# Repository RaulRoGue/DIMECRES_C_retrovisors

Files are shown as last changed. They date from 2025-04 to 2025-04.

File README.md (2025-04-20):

View this project on [CADLAB.io](https://cadlab.io/project/28966). 

# DIMECRES_C_retrovisors
## Autors
- Nom 1 (@RaulRoGue)
- Nom 2 (@inesquiot)
## Versió - v1.0 ## Curs - Assignatura de Disseny de PCBs amb KiCad - [Curs 2024-2025]

## Objectiu
Dissenyar una placa de circuit imprès (PCB) capaç de gestionar diverses funcions relacionades amb el retrovisor d’un vehicle. Aquesta PCB ha d’incloure les següents característiques:

- Control del plegament i desplegament del retrovisor, mitjançant motors elèctrics que permetin modificar-ne la posició de manera automàtica.

- Ajust de l'orientació del mirall, també motoritzat, per adaptar-lo segons les necessitats del conductor.

- Integració d’un sensor de detecció de punts morts, que alerti el conductor de la presència de vehicles o obstacles en zones de visibilitat reduïda.

- Incorporació d’un sistema de calefacció, per evitar l'entelament del mirall en condicions de fred o humitat.

- Implementació d’una llum indicadora de direcció, sincronitzada amb els intermitents del vehicle per millorar la visibilitat i la seguretat en maniobres.

## Requisits i especificacions
- 3 motors (moviment de mirall vertical i horitzontal, i plegat del retrovisor) amb
els seus finals de carrera.
- Calefactor del mirall.
- Sensor digital de detecció d’angle mort i llum indicadora.

## Diagrama de blocs
Diagrama blocs
## Taula de components
| Descripció | Manufacturer Number | Package | Datasheet | Proveïdor | Unitats |
|---|---|---|---|---|---|
| Driver | L298N | Multipower15 | [Enllaç](https://www.mouser.es/datasheet/2/389/l298-1849437.pdf) | Mouser | 1 |
| Microcontrolador|PIC18F4480| 40-Pin PDIP |[Enllaç](https://www.mouser.es/datasheet/2/268/41159e-3443038.pdf)| Mouser | 1 |
| CAN Transceiver| MCP2551 | Soic-8 |[Enllaç](https://www.mouser.es/datasheet/2/268/20001667G-3441642.pdf)| Mouser | 1 |
| Rele SPDT| FN01B | | [Enllaç](https://docs.rs-online.com/df01/0900766b8158318b.pdf) | RS Amidata | 2 | 
| Rele DPDT | G6S-2F| | [Enllaç](https://docs.rs-online.com/f19f/0900766b813679a7.pdf) | Rs Amidara | 1 | 
| OpAmp | ADA4511-2 | Soic-8 |[Enllaç](https://www.analog.com/media/en/technical-documentation/data-sheets/ada4511-2.pdf) | Analog Devices | 1 |
| Conv. DC/DC Buck | LM2596 | TO-263  | [Enllaç](https://www.ti.com/lit/ds/symlink/lm2596.pdf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) | Texas Instruments | 1 | 
| Regulador 5V | LT1117-5 | TO-263 | [Enllaç](https://www.ti.com/lit/ds/symlink/lm1117.pdf?ts=1742626115453&ref_url=https%253A%252F%252Feu.mouser.com%252F) | Texas Instruments | 1 |
| Diode Schottky | SS3P5 | SMP | [Enllaç](https://www.vishay.com/docs/88997/ss3p5.pdf)| Mouser | 1 | 
| Transistors BJT | DTC144EE-TP |  SOT523 | [Enllaç](https://eu.mouser.com/datasheet/2/258/DTC144EE_SOT_523_-3422355.pdf) | Mouser | 3 | 
| Sensor | CH201 | | [Enllaç](https://www.mouser.com/catalog/specsheets/TDK_10012020_DS-000379-CH201-v1.1.pdf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) | Mouser | 1 |
| Regulador 1.8V | ADM7160 | 5-TSOT | [Enllaç](https://www.analog.com/media/en/technical-documentation/data-sheets/ADM7160.pdf) | Analog Devices | 1 |
| Diodes Circulació | 1N5817 | DO-41 | [Enllaç](https://www.mouser.es/datasheet/2/389/1n5817-1848842.pdf) | Mouser | 3 | 
| Diodes Drivers | 1N5822 | DO-201AD | [Enllaç](https://www.mouser.es/datasheet/2/389/1n5822-1848813.pdf) | Mouser | 8 | 
| Convertidor voltatge | LSF0002 | DTQ(X2S0N) | [Enllaç](https://www.ti.com/lit/ds/symlink/lsf0002.pdf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) | Texas Instruments | 1 |
| Led Angle Mort | LS R976-NR-1 | 0805 (2012) | [Enllaç](https://www.mouser.es/datasheet/2/588/asset_pdf_5057921-3418987.pdf) | Mouser | 1 | 
| Led Alimentació | LTST-C170GKT | 0805 (2012) | [Enllaç](https://www.mouser.es/datasheet/2/239/Lite_On_LTST_C170GKT-1175235.pdf) | Mouser | 1 | 
| Connectors | 1548128 | | [Enllaç](https://www.mouser.es/ProductDetail/Phoenix-Contact/1548128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) | Mouser | 6 | 
| Botons | PTS647SN50SMTR2 LFS | | [Enllaç](https://www.ckswitches.com/media/2567/pts647.pdf) | Mouser | 6 | 
| Cristall | ABLS2-4.000MHz-B4Y-T | HC-49-US | [Enllaç](https://www.mouser.es/datasheet/2/3/ABLS2-1775116.pdf) | Mouser | 1 | 
| DE9 | DE-9S-1A8N-A197 | | [Enllaç](https://www.mouser.es/datasheet/2/578/original-3313093.pdf) | Mouser | 2 | 
| 
## Funcionalitats 
- [ ] Funció 1
- [ ] Funció 2
- [ ] Funció 3

## Historial de canvis 
| Data | Autor | Branch | Descripció |
|---|---|---|---|
| 2025-03-20 | Raul | `main` | Creació del projecte |
| 2025-03-21 | Raul | `main` | Llista materials | 
| 2025-03-23 | Raul | `main` | Sch. Regulador+Driver |
| 2025-03-23 | Ines | `main` | Sch. Microcontrolador |
| 2025-03-23 | Ines | `main` | Bus Can |
| 2025-03-23 | Ines | `main` | Modificacio Sch - afegit resistències i capacitancies |
| 2025-03-25 | Raul | `main` |Act. Sch. |
| 2025-03-29 | Raul | `main` | Sch. Def. |
| 2025-03-31 | Raul | `main` | Layout v1 | 
| 2025-03-31 | Ines | `main` | Diagrama de Blocs definitiu |

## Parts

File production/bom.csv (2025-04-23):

Designator | Footprint | Quantity | Value | LCSC Part #
C1 | CP_Radial_D6.3mm_P2.50mm | 1 | 120u
C10, C11, C14, C20, C4, C8, C9 | 1206 | 7 | 100n
C12, C13 | 0805 | 2 | 15p
C15, C16, C17 | 1206 | 3 | 47n
C18 | 0805 | 1 | 1n
C19, C3 | 1206 | 2 | 4u7
C2, C6 | CP_Radial_D6.3mm_P2.50mm | 2 | 470u
C21, C22 | 0805 | 2 | 33n
C23 | 0805 | 1 | 100n
C5 | 0805 | 1 | 100u
D1 | D_SMP_DO-220AA | 1 | SS3P5
D10, D11, D12, D13, D14, D7, D8, D9 | D_DO-201AD_P15.24mm_Horizontal | 8 | 1N5822
D2 | 0805 | 1 | R_LED
D3, D5, D6 | D_DO-41_SOD81_P10.16mm_Horizontal | 3 | 1N5817
D4 | 0805 | 1 | G_LED
J10 | TerminalBlock_TE_282834-2_1x02_5,08mm_Horizontal | 1 | Vbat
J2, J5 | DSUB-9_Socket_Vertical_P2.77x2.84mm_MountingHoles | 2 | DE9_Pins
J3 | PinHeader_1x05_P2.54mm_Vertical | 1 | Conn_01x05_Pin
J4 | TerminalBlock_TE_282834-2_1x02_5,08mm_Horizontal | 1 | Motor3
J6 | TerminalBlock_TE_282834-2_1x02_5,08mm_Horizontal | 1 | Intermitente
J7 | TerminalBlock_TE_282834-2_1x02_5,08mm_Horizontal | 1 | Calentador
J8 | TerminalBlock_TE_282834-2_1x02_5,08mm_Horizontal | 1 | Motor2
J9 | TerminalBlock_TE_282834-2_1x02_5,08mm_Horizontal | 1 | Motor1
JP1 | PinHeader_1x03_P2.54mm_Vertical | 1 | Jumper_3_Open
L1 | 0805 | 1 | 33u
Q1, Q2, Q3 | SOT-523 | 3 | DTC144E
R1, R12, R14, R16, R17 | 1206 | 5 | 1k
R10, R11, R25, R26 | 0805 | 4 | 1K
R13, R15, R18, R19 | 1206 | 4 | 100k
R2 | 1206 | 1 | 3k9
R20 | 0805 | 1 | 100
R21 | 0805 | 1 | 150
R22, R23 | 0805 | 2 | 120
R24 | 0805 | 1 | 180
R3 | 1206 | 1 | 10k
R4, R5 | 1206 | 2 | 50m
R6 | 0805 | 1 | 60
R7 | 1206 | 1 | 15k
R9 | 1206 | 1 | 33k
SW1 | Relay_DPDT_Omron_G6S-2F | 1 | SW_DPDT_G6S
SW10 | SW_SPST_PTS647_Sx38 | 1 | SW_Push
SW2 | SW_SPST_PTS647_Sx38 | 1 | UN/FOLD
SW3 | SW_SPST_PTS647_Sx38 | 1 | HEAT
SW4 | SW_SPST_PTS647_Sx38 | 1 | UP
SW5 | SW_SPST_PTS647_Sx38 | 1 | DOWN
SW6 | SW_SPST_PTS647_Sx38 | 1 | LEFT
SW7 | SW_SPST_PTS647_Sx38 | 1 | RIGHT
SW8, SW9 | Relay_SPDT_HsinDa_Y14 | 2 | FN01B
U1 | CH201 | 1 | CH201
U10 | TO-263-3_TabPin2 | 1 | LM1117DT-5.0
U2 | TSOT-23-5 | 1 | ADM7160
U3 | TO-263-5_TabPin3 | 1 | LM2596S-ADJ
U4 | TO-220-15_P2.54x5.08mm_StaggerOdd_Lead4.58mm_Vertical | 1 | L298N
U5 | SOIC-8_3.9x4.9mm_P1.27mm | 1 | MCP2551-I-SN
U6 | SOIC-8_3.9x4.9mm_P1.27mm | 1 | ADA4511-2
U7 | DIP-40_W15.24mm | 1 | PIC18F4480-IP
U8 | LSF0002 | 1 | LSF0002
Y1 | Crystal_SMD_HC49-SD_Practica3 | 1 | Crystal

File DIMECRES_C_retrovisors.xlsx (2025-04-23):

Reference | Value | Datasheet | Footprint | Qty | DNP | LSCS
C1 | 120u | ~ | Capacitor_THT:CP_Radial_D6.3mm_P2.50mm | 1 |  | C261376
C2,C6 | 470u | ~ | Capacitor_THT:CP_Radial_D6.3mm_P2.50mm | 2 |  | C43328
C3,C19 | 4u7 | ~ | Capacitor_SMD:C_1206_3216Metric_Pad1.33x1.80mm_HandSolder | 2 |  | C1872 | TAULA DE PREUS DE COMPONENTS PER NÚMERO DE UNITATS
C4,C8,C9,C10,C11,C14,C20 | 100n | ~ | Capacitor_SMD:C_1206_3216Metric_Pad1.33x1.80mm_HandSolder | 7 |  | C1945
C5 | 100u | ~ | Capacitor_SMD:C_0805_2012Metric_Pad1.18x1.45mm_HandSolder | 1 |  | C141660 | unitats | x10 | x50 | x1.000 | x20.000
C12,C13 | 15p | ~ | Capacitor_SMD:C_0805_2012Metric_Pad1.18x1.45mm_HandSolder | 2 |  | C63339 | COMPONENTS (€/unitat)
C15,C16,C17 | 47n | ~ | Capacitor_SMD:C_1206_3216Metric_Pad1.33x1.80mm_HandSolder | 3 |  | C1870 | Microcontrolador: PIC18F4480-I/P | 7.270 | 7.270 | 7.270 | 7.270 | *DigiKey | PIC18F4480 (https://www.digikey.es/en/products/detail/microchip-technology/PIC18F4480-I-P/718243)
C18 | 1n | ~ | Capacitor_SMD:C_0805_2012Metric_Pad1.18x1.45mm_HandSolder | 1 |  | C1791 | Driver: L298N | 8.524 | 7.938 | 6.651 | 6.651 | *DigiKey | L298N (https://www.digikey.es/es/products/detail/stmicroelectronics/L298N/585918)
C21,C22 | 33n | ~ | Capacitor_SMD:C_0805_2012Metric_Pad1.18x1.45mm_HandSolder | 2 |  | C107150 | CAN Transceiver: MCP2551 | 1.250 | 1.042 | 1.026 | 1.026 | *DigiKey | MCP2551 (https://www.digikey.es/es/products/detail/microchip-technology/MCP2551-I-SN/509452)
C23 | 100n | ~ | Capacitor_SMD:C_0805_2012Metric_Pad1.18x1.45mm_HandSolder | 1 |  | C1711 | Rele SPDT: FN01B | 2.480 | 2.210 | 1.480 | 1.480 | *RS Amidata | FN01B (https://es.rs-online.com/web/p/reles-de-senal/0476757?searchId=290cb22d-e97d-4f3a-a323-c20805e55914&gb=s)
D1 | SS3P5 | ~ | Diode_SMD:D_SMP_DO-220AA | 1 |  | C7369110 | Rele DPDT: G6S-2F-DC5 | 3.209 | 2.960 | 2.545 | 2.545 | *DigiKey | G6S-2F-DC5 (https://www.digikey.es/es/products/detail/omron-electronics-inc-emc-div/G6S-2F-DC5/27496)
D2 | R_LED | ~ | LED_SMD:LED_0805_2012Metric_Pad1.15x1.40mm_HandSolder | 1 |  | C2899997 | OpAmp: ADA4511-2 | 2.210 | 2.210 | 1.210 | 1.170 | *DigiKey | ADA4511-2 (https://www.mouser.es/ProductDetail/Analog-Devices/ADA4511-2ARZ?qs=dbcCsuKDzFWR7kRkdhPUdQ%3D%3D)
D3,D5,D6 | 1N5817 | http://www.vishay.com/docs/88525/1n5817.pdf | Diode_THT:D_DO-41_SOD81_P10.16mm_Horizontal | 3 |  | C698892 | Conv. DC/DC Buck: LM2596T-ADJ/NOPB | 4.190 | 3.880 | 3.120 | 3.060 | *Mouser | LM2596ADJ (https://www.mouser.es/ProductDetail/Texas-Instruments/LM2596SX-ADJ-NOPB?qs=X1J7HmVL2ZGDNERsF5YBdQ%3D%3D)
D4 | G_LED | ~ | LED_SMD:LED_0805_2012Metric_Pad1.15x1.40mm_HandSolder | 1 |  | C125090 | Regulador 5V : LT1117CST-5 | 5.785 | 4.599 | 3.737 | 3.710 | *DigiKey | LT1117 (https://www.digikey.es/en/products/detail/analog-devices-inc/LT1117CM-5-PBF/)
D7,D8,D9,D10,D11,D12,D13,D14 | 1N5822 | http://www.vishay.com/docs/88526/1n5820.pdf | Diode_THT:D_DO-201AD_P15.24mm_Horizontal | 8 |  |  | Diode Schottky: SS3P5-M3 | 0.154 | 0.154 | 0.100 | 0.071 | *DigiKey | SS3P5 (https://www.digikey.es/en/products/detail/vishay-general-semiconductor-diodes-division/SS3P5HM3-84A/4495002)
J2,J5 | DE9_Pins | ~ | Connector_Dsub:DSUB-9_Socket_Vertical_P2.77x2.84mm_MountingHoles | 2 |  | C77831 | Transistors BJT: DTC144EE-TP | 0.128 | 0.128 | 0.051 | 0.031 | *DigiKey | DTC144EE (https://www.digikey.es/en/products/detail/mcc-micro-commercial-components/DTC144EE-TP/857327)
J3 | Conn_01x05_Pin | ~ | Connector_PinHeader_2.54mm:PinHeader_1x05_P2.54mm_Vertical | 1 |  | C2337 | Sensor: CH201 | 5.420 | 5.420 | 4.980 | 4.980 | *Mouser | CH201 (https://www.mouser.es/ProductDetail/TDK-InvenSense/CH201-00ABR?qs=hWgE7mdIu5SG9AjHdakrVw%3D%3D)
J4 | Motor3 | ~ | PracticasKiCad:TerminalBlock_TE_282834-2_1x02_5,08mm_Horizontal | 1 |  | C9900170820 | Regulador 1.8V: ADM7160AUJZ-1.8-R | 1.580 | 1.390 | 0.826 | 0.754 | *Mouser | ADM7160 (https://www.mouser.es/ProductDetail/Analog-Devices/ADM7160AUJZ-1.8-R7?qs=%252BrH4t%252BeVZ2NHqIoVkrMpCQ%3D%3D)
J6 | Intermitente | ~ | PracticasKiCad:TerminalBlock_TE_282834-2_1x02_5,08mm_Horizontal | 1 |  | C9900170820 | Diodes Circulació: 1N5817 | 0.165 | 0.165 | 0.089 | 0.046 | *DigiKey | 1N5817 (https://www.digikey.es/en/products/detail/stmicroelectronics/1N5817/770963)
J7 | Calentador | ~ | PracticasKiCad:TerminalBlock_TE_282834-2_1x02_5,08mm_Horizontal | 1 |  | C9900170820 | Diodes Drivers: 1N5822 | 0.204 | 0.204 | 0.121 | 0.090 | *Mouser | 1N5822 (https://www.mouser.es/ProductDetail/STMicroelectronics/1N5822?qs=JV7lzlMm3yJ50hlrGV6%252BnQ%3D%3D)
J8 | Motor2 | ~ | PracticasKiCad:TerminalBlock_TE_282834-2_1x02_5,08mm_Horizontal | 1 |  | C9900170820 | Led Angle Mort: Ls R976-NR-1 | 0.102 | 0.102 | 0.051 | 0.037 | *DigiKey | LED ROIG (https://www.digikey.es/en/products/detail/ams-osram-usa-inc/LS-R976-NR-1-0-20-R18/1227987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)
J9 | Motor1 | ~ | PracticasKiCad:TerminalBlock_TE_282834-2_1x02_5,08mm_Horizontal | 1 |  | C9900170820 | Led Alimentació: LTST-C170GKT | 0.105 | 0.105 | 0.052 | 0.038 | *Mouser | LED VERD (https://www.mouser.es/ProductDetail/LITEON/LTST-C170GKT?qs=%2FSqKn2EfXQSV5aRij3YIfQ%3D%3D)
J10 | Vbat | ~ | PracticasKiCad:TerminalBlock_TE_282834-2_1x02_5,08mm_Horizontal | 1 |  | C9900170820 | Connectors | 0.939 | 0.939 | 0.939 | 0.939 | *Mouser | CONNECTOR (https://www.mouser.es/ProductDetail/Phoenix-Contact/1548128?qs=ulEaXIWI0c87QOzP9yohxA%3D%3D)
JP1 | Jumper_3_Open | ~ | Connector_PinHeader_2.54mm:PinHeader_1x03_P2.54mm_Vertical | 1 |  | C2337 | Botons | 0.179 | 0.179 | 0.153 | 0.105 | *Mouser | BOTONS (https://www.mouser.es/ProductDetail/CK/PTS647SN50SMTR2-LFS?qs=Imq1NPwxi75fXjNwFzf38w%3D%3D)
L1 | 33u | ~ | Inductor_SMD:L_0805_2012Metric_Pad1.05x1.20mm_HandSolder | 1 |  | C412010 | Convertidor Voltatge : LSF0002 | 0.248 | 0.221 | 0.168 | 0.137 | *Mouser | LSF0002 (https://www.mouser.es/ProductDetail/Texas-Instruments/LSF0002DTQR?qs=i8QVZAFTkqSFGlrqVB4k9w%3D%3D)
Q1,Q2,Q3 | DTC144E |  | Package_TO_SOT_SMD:SOT-523 | 3 |  | C17296322 | Cristall | 0.279 | 0.253 | 0.207 | 0.171 | *Mouser | CRISTALL (https://www.mouser.es/ProductDetail/ABRACON/ABLS2-4.000MHz-B4Y-T?qs=DZ%2FvJMgWWIuMViH9oNkyhA%3D%3D)
R1,R12,R14,R16,R17 | 1k | ~ | Resistor_SMD:R_1206_3216Metric_Pad1.30x1.75mm_HandSolder | 5 |  | C4410 | DE9 | 5.333 | 4.760 | 4.531 | 4.531 | *DigiKey | DE9 (https://www.digikey.es/en/products/detail/jae-electronics/DE-9SF-T-N/5397179)
R2 | 3k9 | ~ | Resistor_SMD:R_1206_3216Metric_Pad1.30x1.75mm_HandSolder | 1 |  | C26042 | TOTAL COMPONENTS: (€/placa) | 65.35 | 60.882 | 52.0599 | 50.9639
R3 | 10k | ~ | Resistor_SMD:R_1206_3216Metric_Pad1.30x1.75mm_HandSolder | 1 |  | C17902 | TOTAL COMPONENTS | 653.5 | 3044.1 | 52059.9 | 1019278
R4,R5 | 50m | ~ | Resistor_SMD:R_1206_3216Metric_Pad1.30x1.75mm_HandSolder | 2 |  | C335234
R6 | 60 | ~ | Resistor_SMD:R_0805_2012Metric_Pad1.20x1.40mm_HandSolder | 1 |  | C2767521
R7 | 15k | ~ | Resistor_SMD:R_1206_3216Metric_Pad1.30x1.75mm_HandSolder | 1 |  | C25828
R9 | 33k | ~ | Resistor_SMD:R_1206_3216Metric_Pad1.30x1.75mm_HandSolder | 1 |  | C25660
R10,R11,R25,R26 | 1K | ~ | Resistor_SMD:R_0805_2012Metric_Pad1.20x1.40mm_HandSolder | 4 |  | C25623
R13,R15,R18,R19 | 100k | ~ | Resistor_SMD:R_1206_3216Metric_Pad1.30x1.75mm_HandSolder | 4 |  | C25647
R20 | 100 | ~ | Resistor_SMD:R_0805_2012Metric_Pad1.20x1.40mm_HandSolder | 1 |  | C25277
R21 | 150 | ~ | Resistor_SMD:R_0805_2012Metric_Pad1.20x1.40mm_HandSolder | 1 |  | C25283
R22,R23 | 120 | ~ | Resistor_SMD:R_0805_2012Metric_Pad1.20x1.40mm_HandSolder | 2 |  | C25280 | TAULADE PREUS PER CADA PCB DEPENENT DEL TIPUS DE MUNTATGE
R24 | 180 | ~ | Resistor_SMD:R_0805_2012Metric_Pad1.20x1.40mm_HandSolder | 1 |  | C1339
SW1 | SW_DPDT_G6S | ~ | Relay_SMD:Relay_DPDT_Omron_G6S-2F | 1 |  | C16707 |  | muntatge manual amb terminis curts d'entrega |  |  |  | muntatge industrial amb temps de lliurament llarg |  |  | PCB | Capacitats | Resistències | Inductància | Altres | Total
SW2 | UN/FOLD | ~ | Button_Switch_SMD:SW_SPST_PTS647_Sx38 | 1 |  | C2799414 | unitats | x10 |  | x50 |  | x1.000 |  | x20.000 | x1000 | - | - | - | 43876.5 | 43876.5
SW3 | HEAT | ~ | Button_Switch_SMD:SW_SPST_PTS647_Sx38 | 1 |  | C2799414 | Components | 653.5 |  | 3044.1 |  | 43876.5 |  | 928538 | x20000 | 7942 | 52 | 364 | 920180 | 928538
SW4 | UP | ~ | Button_Switch_SMD:SW_SPST_PTS647_Sx38 | 1 |  | C2799414 | PCB | 18.8 |  | 64.7 |  | 502.8 |  | 7749.8
SW5 | DOWN | ~ | Button_Switch_SMD:SW_SPST_PTS647_Sx38 | 1 |  | C2799414 | Stencils | 7 |  | 7 |  | x |  | x
SW6 | LEFT | ~ | Button_Switch_SMD:SW_SPST_PTS647_Sx38 | 1 |  | C2799414 | Muntatge | x |  | x |  | 3515.34 |  | 9097.65
SW7 | RIGHT | ~ | Button_Switch_SMD:SW_SPST_PTS647_Sx38 | 1 |  | C2799414 | TOTAL PCB | 679.3 |  | 3115.8 |  | 47894.64 |  | 945385.45
SW8,SW9 | FN01B |  | Relay_THT:Relay_SPDT_HsinDa_Y14 | 2 |  |  | PREU Unitari | 67.93 |  | 62.316 |  | 47.89464 |  | 47.2692725
SW10 | SW_Push | ~ | Button_Switch_SMD:SW_SPST_PTS647_Sx38 | 1 |  | C2799414
U1 | CH201 |  | PracticasKiCad:CH201 | 1 |  | C1513114
U2 | ADM7160 |  | Package_TO_SOT_SMD:TSOT-23-5 | 1 |  | C658467
U3 | LM2596S-ADJ | http://www.ti.com/lit/ds/symlink/lm2596.pdf | Package_TO_SOT_SMD:TO-263-5_TabPin3 | 1 |  | C9900011164
U4 | L298N | http://www.st.com/st-web-ui/static/active/en/resource/technical/document/datasheet/CD00000240.pdf | Package_TO_SOT_THT:TO-220-15_P2.54x5.08mm_StaggerOdd_Lead4.58mm_Vertical | 1 |  | C19922
U5 | MCP2551-I-SN | http://ww1.microchip.com/downloads/en/devicedoc/21667d.pdf | Package_SO:SOIC-8_3.9x4.9mm_P1.27mm | 1 |  | C7376
U6 | ADA4511-2 | https://www.analog.com/media/en/technical-documentation/data-sheets/ada4522-1_4522-2_4522-4.pdf | Package_SO:SOIC-8_3.9x4.9mm_P1.27mm | 1 |  | C22441753
U7 | PIC18F4480-IP | http://ww1.microchip.com/downloads/en/DeviceDoc/39637d.pdf | Package_DIP:DIP-40_W15.24mm | 1 |  | C647983
U8 | LSF0002 |  | PracticasKiCad:LSF0002 | 1
U10 | LM1117DT-5.0 | http://www.ti.com/lit/ds/symlink/lm1117.pdf | Package_TO_SOT_SMD:TO-263-3_TabPin2 | 1 |  | C2867691
Y1 | Crystal | ~ | PracticasKiCad:Crystal_SMD_HC49-SD_Practica3 | 1 |  | C5542957

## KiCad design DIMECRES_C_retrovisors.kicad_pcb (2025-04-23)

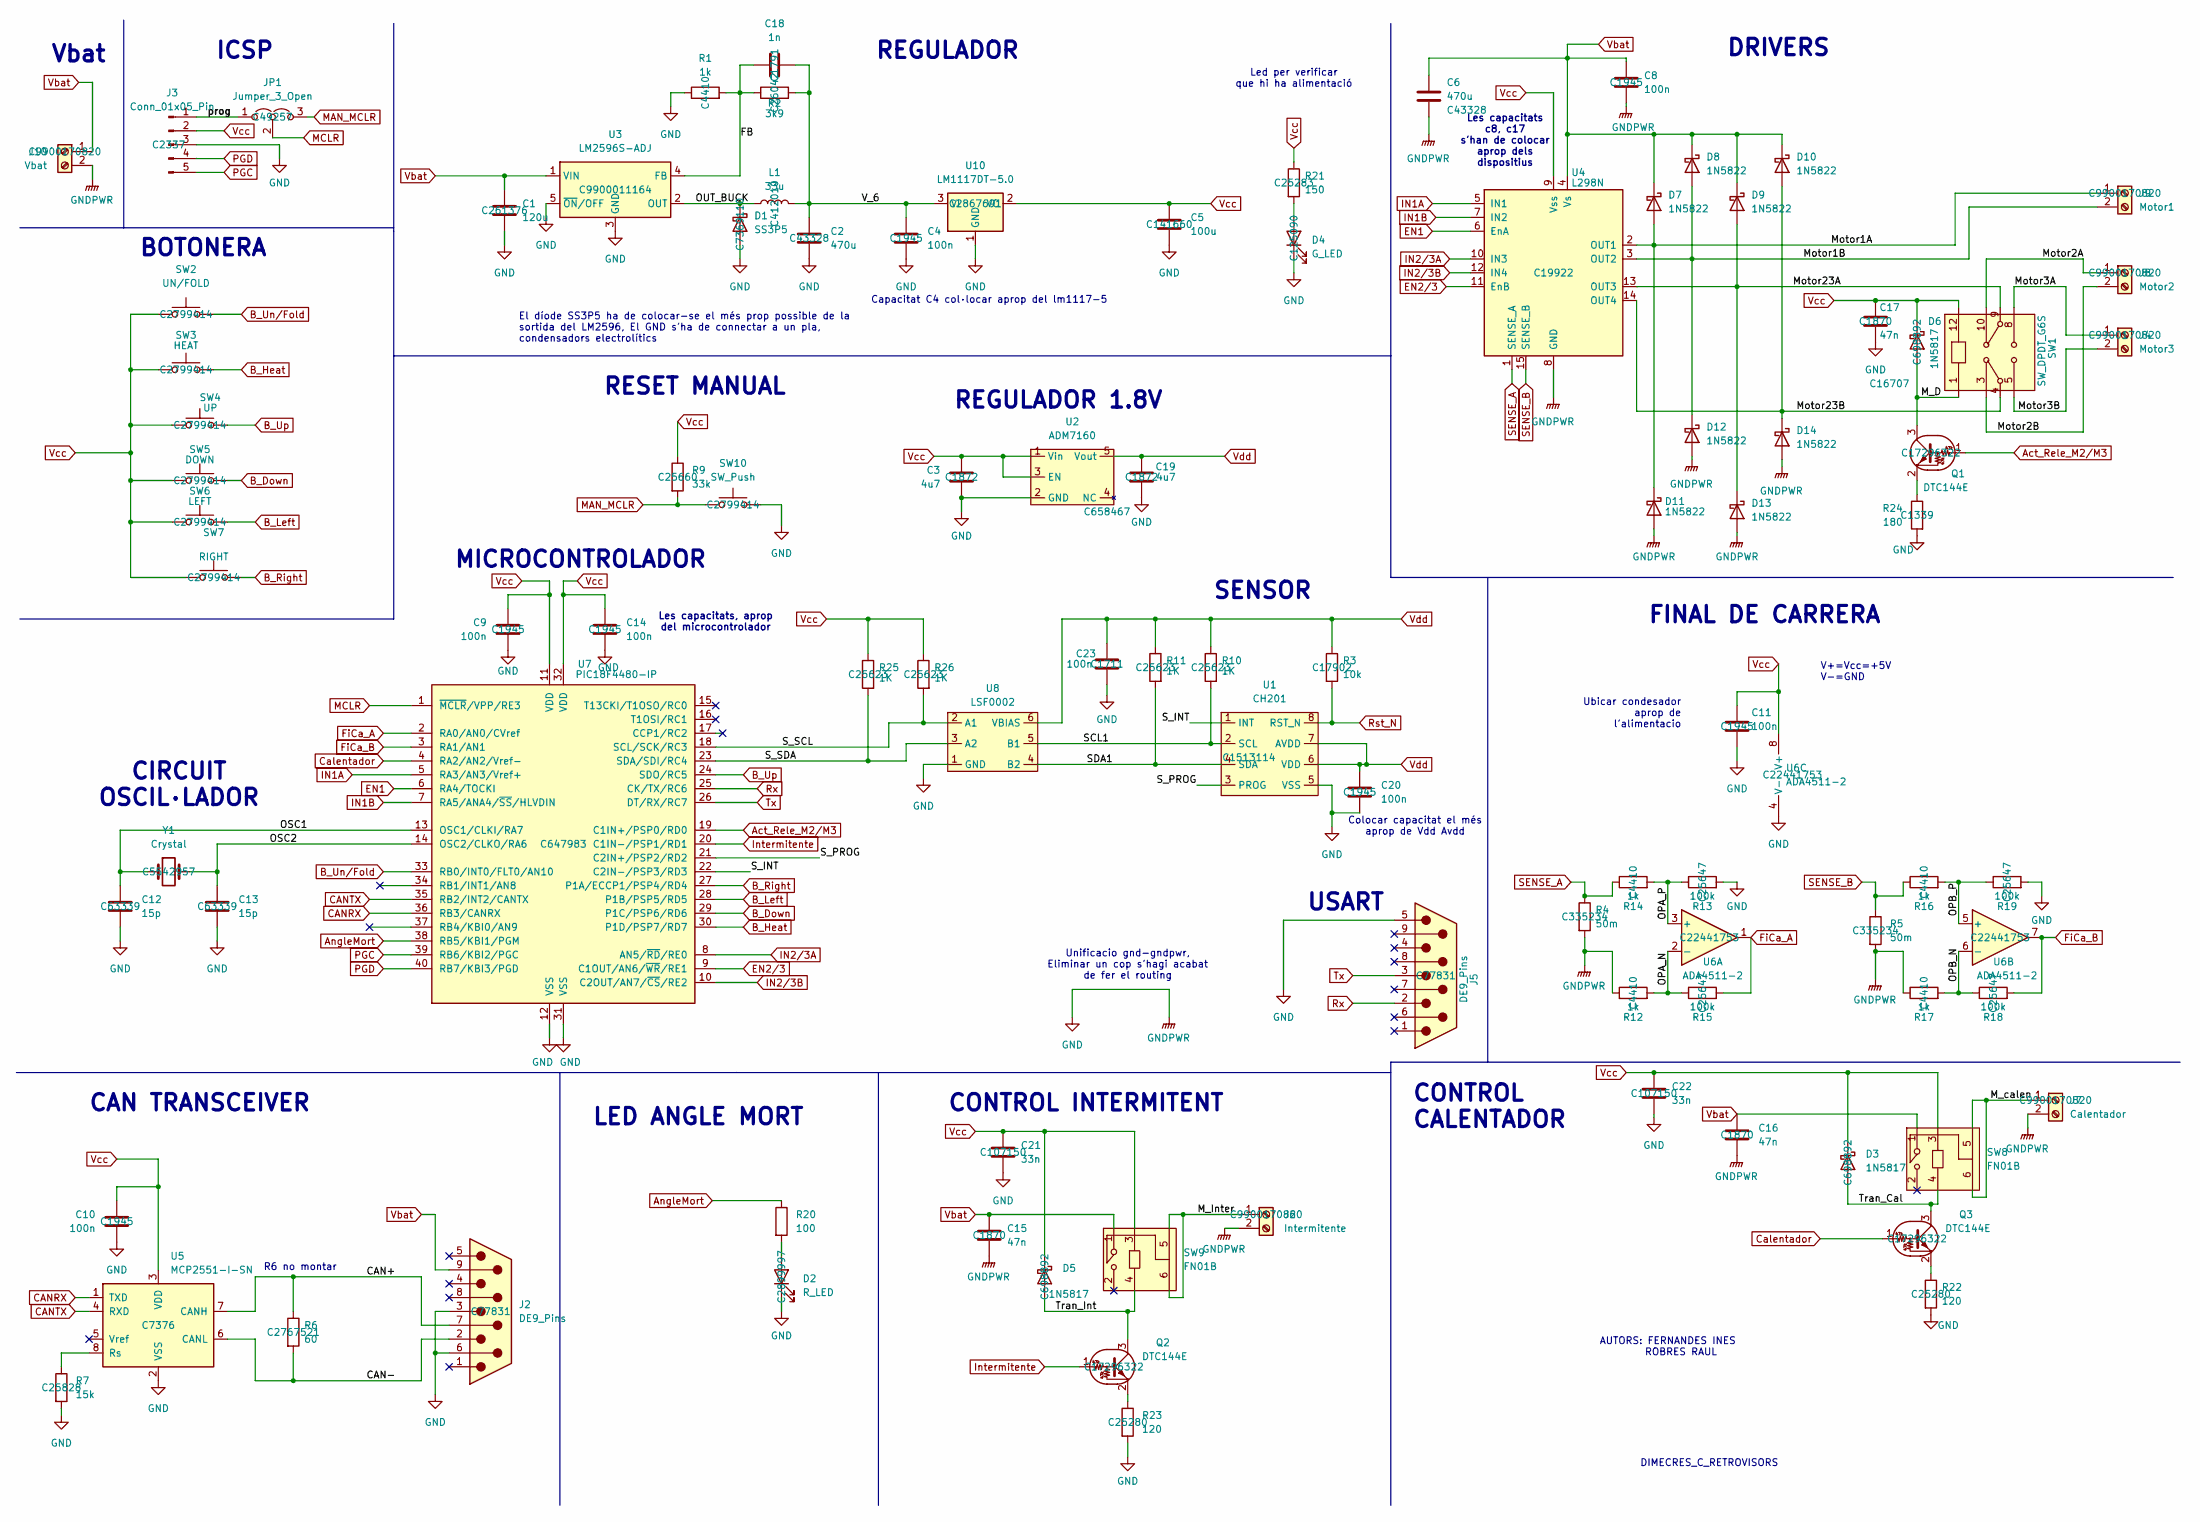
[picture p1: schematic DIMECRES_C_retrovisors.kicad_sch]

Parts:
C1: 120u; CP_Radial_D6.3mm_P2.50mm
C2, C6: 470u; CP_Radial_D6.3mm_P2.50mm
C3, C19: 4u7; C_1206_3216Metric_Pad1.33x1.80mm_HandSolder
C4, C8, C9, C10, C11, C14, C20: 100n; C_1206_3216Metric_Pad1.33x1.80mm_HandSolder
C5: 100u; C_0805_2012Metric_Pad1.18x1.45mm_HandSolder
C12, C13: 15p; C_0805_2012Metric_Pad1.18x1.45mm_HandSolder
C15, C16, C17: 47n; C_1206_3216Metric_Pad1.33x1.80mm_HandSolder
C18: 1n; C_0805_2012Metric_Pad1.18x1.45mm_HandSolder
C21, C22: 33n; C_0805_2012Metric_Pad1.18x1.45mm_HandSolder
C23: 100n; C_0805_2012Metric_Pad1.18x1.45mm_HandSolder
D1: SS3P5; D_SMP_DO-220AA
D2: R_LED; LED_0805_2012Metric_Pad1.15x1.40mm_HandSolder
D3, D5, D6: 1N5817; D_DO-41_SOD81_P10.16mm_Horizontal
D4: G_LED; LED_0805_2012Metric_Pad1.15x1.40mm_HandSolder
D7, D8, D9, D10, D11, D12, D13, D14: 1N5822; D_DO-201AD_P15.24mm_Horizontal
J2, J5: DE9_Pins; DSUB-9_Socket_Vertical_P2.77x2.84mm_MountingHoles
J3: Conn_01x05_Pin; PinHeader_1x05_P2.54mm_Vertical
J4: Motor3; TerminalBlock_TE_282834-2_1x02_5,08mm_Horizontal
J6: Intermitente; TerminalBlock_TE_282834-2_1x02_5,08mm_Horizontal
J7: Calentador; TerminalBlock_TE_282834-2_1x02_5,08mm_Horizontal
J8: Motor2; TerminalBlock_TE_282834-2_1x02_5,08mm_Horizontal
J9: Motor1; TerminalBlock_TE_282834-2_1x02_5,08mm_Horizontal
J10: Vbat; TerminalBlock_TE_282834-2_1x02_5,08mm_Horizontal
JP1: Jumper_3_Open; PinHeader_1x03_P2.54mm_Vertical
L1: 33u; L_0805_2012Metric_Pad1.05x1.20mm_HandSolder
Q1, Q2, Q3: DTC144E; SOT-523
R1, R12, R14, R16, R17: 1k; R_1206_3216Metric_Pad1.30x1.75mm_HandSolder
R2: 3k9; R_1206_3216Metric_Pad1.30x1.75mm_HandSolder
R3: 10k; R_1206_3216Metric_Pad1.30x1.75mm_HandSolder
R4, R5: 50m; R_1206_3216Metric_Pad1.30x1.75mm_HandSolder
R6: 60; R_0805_2012Metric_Pad1.20x1.40mm_HandSolder
R7: 15k; R_1206_3216Metric_Pad1.30x1.75mm_HandSolder
R9: 33k; R_1206_3216Metric_Pad1.30x1.75mm_HandSolder
R10, R11, R25, R26: 1K; R_0805_2012Metric_Pad1.20x1.40mm_HandSolder
R13, R15, R18, R19: 100k; R_1206_3216Metric_Pad1.30x1.75mm_HandSolder
R20: 100; R_0805_2012Metric_Pad1.20x1.40mm_HandSolder
R21: 150; R_0805_2012Metric_Pad1.20x1.40mm_HandSolder
R22, R23: 120; R_0805_2012Metric_Pad1.20x1.40mm_HandSolder
R24: 180; R_0805_2012Metric_Pad1.20x1.40mm_HandSolder
SW1: SW_DPDT_G6S; Relay_DPDT_Omron_G6S-2F
SW2: UN/FOLD; SW_SPST_PTS647_Sx38
SW3: HEAT; SW_SPST_PTS647_Sx38
SW4: UP; SW_SPST_PTS647_Sx38
SW5: DOWN; SW_SPST_PTS647_Sx38
SW6: LEFT; SW_SPST_PTS647_Sx38
SW7: RIGHT; SW_SPST_PTS647_Sx38
SW8, SW9: FN01B; Relay_SPDT_HsinDa_Y14
SW10: SW_Push; SW_SPST_PTS647_Sx38
U1: CH201
U2: ADM7160; TSOT-23-5
U3: LM2596S-ADJ; TO-263-5_TabPin3
U4: L298N; TO-220-15_P2.54x5.08mm_StaggerOdd_Lead4.58mm_Vertical
U5: MCP2551-I-SN; SOIC-8_3.9x4.9mm_P1.27mm
U6: ADA4511-2; SOIC-8_3.9x4.9mm_P1.27mm
U7: PIC18F4480-IP; DIP-40_W15.24mm
U8: LSF0002
U10: LM1117DT-5.0; TO-263-3_TabPin2
Y1: Crystal; Crystal_SMD_HC49-SD_Practica3

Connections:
/CAN+: J2.7, R6.1, U5.7 (CANH)
/CAN-: J2.2, R6.2, U5.6 (CANL)
/FB: C18.1, R1.2, R2.1, U3.4 (FB)
/M_D: D6.2 (A), Q1.3 (C), SW1.1
/M_Inter: J6.1, SW9.5, SW9.6
/M_calen: J7.1, SW8.5, SW8.6
/Motor1A: D7.2 (A), D11.1 (K), J9.1, U4.2 (OUT1)
/Motor1B: D8.2 (A), D12.1 (K), J9.2, U4.3 (OUT2)
/Motor2A: J8.1, SW1.10
/Motor2B: J8.2, SW1.3
/Motor3A: J4.1, SW1.8
/Motor3B: J4.2, SW1.5
/Motor23A: D9.2 (A), D13.1 (K), SW1.9, U4.13 (OUT3)
/Motor23B: D10.2 (A), D14.1 (K), SW1.4, U4.14 (OUT4)
/OPA_N: R12.2, R15.1, U6.2 (-)
/OPA_P: R13.1, R14.2, U6.3 (+)
/OPB_N: R17.2, R18.1, U6.6 (-)
/OPB_P: R16.2, R19.1, U6.5 (+)
/OSC1: C12.1, U7.13 (OSC1/CLKI/RA7), Y1.1
/OSC2: C13.1, U7.14 (OSC2/CLKO/RA6), Y1.2
/OUT_BUCK: D1.1 (K), L1.1, U3.2 (OUT)
/SCL1: R10.2, U1.2 (SCL), U8.5 (B1)
/SDA1: R11.2, U1.4 (SDA), U8.4 (B2)
/S_INT: U1.1 (INT), U7.22 (C2IN-/PSP3/RD3)
/S_PROG: U1.3 (PROG), U7.21 (C2IN+/PSP2/RD2)
/S_SCL: R26.2, U7.18 (SCL/SCK/RC3), U8.2 (A1)
/S_SDA: R25.2, U7.23 (SDA/SDI/RC4), U8.3 (A2)
/Tran_Cal: D3.2 (A), Q3.3 (C), SW8.4
/Tran_Int: D5.2 (A), Q2.3 (C), SW9.4
/V_6: C2.1, C4.1, C18.2, L1.2, R2.2, U10.3 (VI)
/prog: J3.1, JP1.1 (A)
Act_Rele_M2/M3: Q1.1 (B), U7.19 (C1IN+/PSP0/RD0)
AngleMort: R20.1, U7.38 (RB5/KBI1/PGM)
B_Down: SW5.2, U7.29 (P1C/PSP6/RD6)
B_Heat: SW3.2, U7.30 (P1D/PSP7/RD7)
B_Left: SW6.2, U7.28 (P1B/PSP5/RD5)
B_Right: SW7.2, U7.27 (P1A/ECCP1/PSP4/RD4)
B_Un/Fold: SW2.2, U7.33 (RB0/INT0/FLT0/AN10)
B_Up: SW4.2, U7.24 (SDO/RC5)
CANRX: U5.1 (TXD), U7.36 (RB3/CANRX)
CANTX: U5.4 (RXD), U7.35 (RB2/INT2/CANTX)
Calentador: Q3.1 (B), U7.4 (RA2/AN2/Vref-)
EN1: U4.6 (EnA), U7.6 (RA4/TOCKI)
EN2/3: U4.11 (EnB), U7.9 (C1OUT/AN6/~WR/RE1)
FiCa_A: R15.2, U6.1, U7.2 (RA0/AN0/CVref)
FiCa_B: R18.2, U6.7, U7.3 (RA1/AN1)
GND: C1.2, C2.2, C3.2, C4.2, C5.2, C6.2, C8.2, C9.2, C10.2, C11.2, C12.2, C13.2, C14.2, C15.2, C16.2, C17.2, C19.2, C20.2, C21.2, C22.2, C23.2, D1.2 (A), D2.1 (K), D4.1 (K), D11.2 (A), D12.2 (A), D13.2 (A), D14.2 (A), J2.3, J2.6, J3.3, J5.5, J6.2, J7.2, J10.2, R1.1, R4.2, R5.2, R7.2, R12.1, R13.2, R17.1, R19.2, R22.2, R23.2, R24.2, SW10.2, U1.5 (VSS), U2.2 (GND), U3.3 (GND), U3.5 (~ON/OFF), U4.8 (GND), U5.2 (VSS), U6.4 (V-), U7.12 (VSS), U7.31 (VSS), U8.1 (GND), U10.1 (GND)
IN1A: U4.5 (IN1), U7.5 (RA3/AN3/Vref+)
IN1B: U4.7 (IN2), U7.7 (RA5/ANA4/~SS/HLVDIN)
IN2/3A: U4.10 (IN3), U7.8 (AN5/~RD/RE0)
IN2/3B: U4.12 (IN4), U7.10 (C2OUT/AN7/~CS/RE2)
Intermitente: Q2.1 (B), U7.20 (C1IN-/PSP1/RD1)
MAN_MCLR: JP1.3 (B), R9.2, SW10.1
MCLR: JP1.2 (C), U7.1 (~MCLR/VPP/RE3)
unnamed: D2.2 (A), R20.2
unnamed: D4.2 (A), R21.2
unnamed: Q1.2 (E), R24.1
unnamed: Q2.2 (E), R23.1
unnamed: Q3.2 (E), R22.1
unnamed: R7.1, U5.8 (Rs)
PGC: J3.5, U7.39 (RB6/KBI2/PGC)
PGD: J3.4, U7.40 (RB7/KBI3/PGD)
Rst_N: R3.2, U1.8 (RST_N)
Rx: J5.2, U7.25 (CK/TX/RC6)
SENSE_A: R4.1, R14.1, U4.1 (SENSE_A)
SENSE_B: R5.1, R16.1, U4.15 (SENSE_B)
Tx: J5.3, U7.26 (DT/RX/RC7)
Vbat: C1.1, C6.1, C8.1, C15.1, C16.1, D7.1 (K), D8.1 (K), D9.1 (K), D10.1 (K), J2.9, J10.1, SW8.1, SW9.1, U3.1 (VIN), U4.4 (Vs)
Vcc: C3.1, C5.1, C9.1, C10.1, C11.1, C14.1, C17.1, C21.1, C22.1, D3.1 (K), D5.1 (K), D6.1 (K), J3.2, R9.1, R21.1, R25.1, R26.1, SW1.12, SW2.1, SW3.1, SW4.1, SW5.1, SW6.1, SW7.1, SW8.3, SW9.3, U2.1 (Vin), U2.3 (EN), U4.9 (Vss), U5.3 (VDD), U6.8 (V+), U7.11 (VDD), U7.32 (VDD), U10.2 (VO)
Vdd: C19.1, C20.1, C23.1, R3.1, R10.1, R11.1, U1.6 (VDD), U1.7 (AVDD), U2.5 (Vout), U8.6 (VBIAS)

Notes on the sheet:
REGULADOR 1.8V
R6 no montar
REGULADOR
Vbat
SENSOR
Unificacio gnd-gndpwr, Eliminar un cop s'hagi acabat de fer el routing
CIRCUIT OSCIL·LADOR
Les capacitats, aprop del microcontrolador
DIMECRES_C_RETROVISORS
MICROCONTROLADOR
DRIVERS
AUTORS: FERNANDES INES ROBRES RAUL
Colocar capacitat el més aprop de Vdd Avdd
CAN TRANSCEIVER
Les capacitats c8, c17 s'han de colocar aprop dels dispositius
CONTROL INTERMITENT
Ubicar condesador aprop de l'alimentacio
V+=Vcc=+5V V-=GND
Led per verificar que hi ha alimentació
LED ANGLE MORT
BOTONERA
Capacitat C4 col·locar aprop del lm1117-5
El díode SS3P5 ha de colocar-se el més prop possible de la sortida del LM2596, El GND s'ha de connectar a un pla, condensadors electrolítics
USART
CONTROL CALENTADOR
RESET MANUAL
FINAL DE CARRERA
ICSP

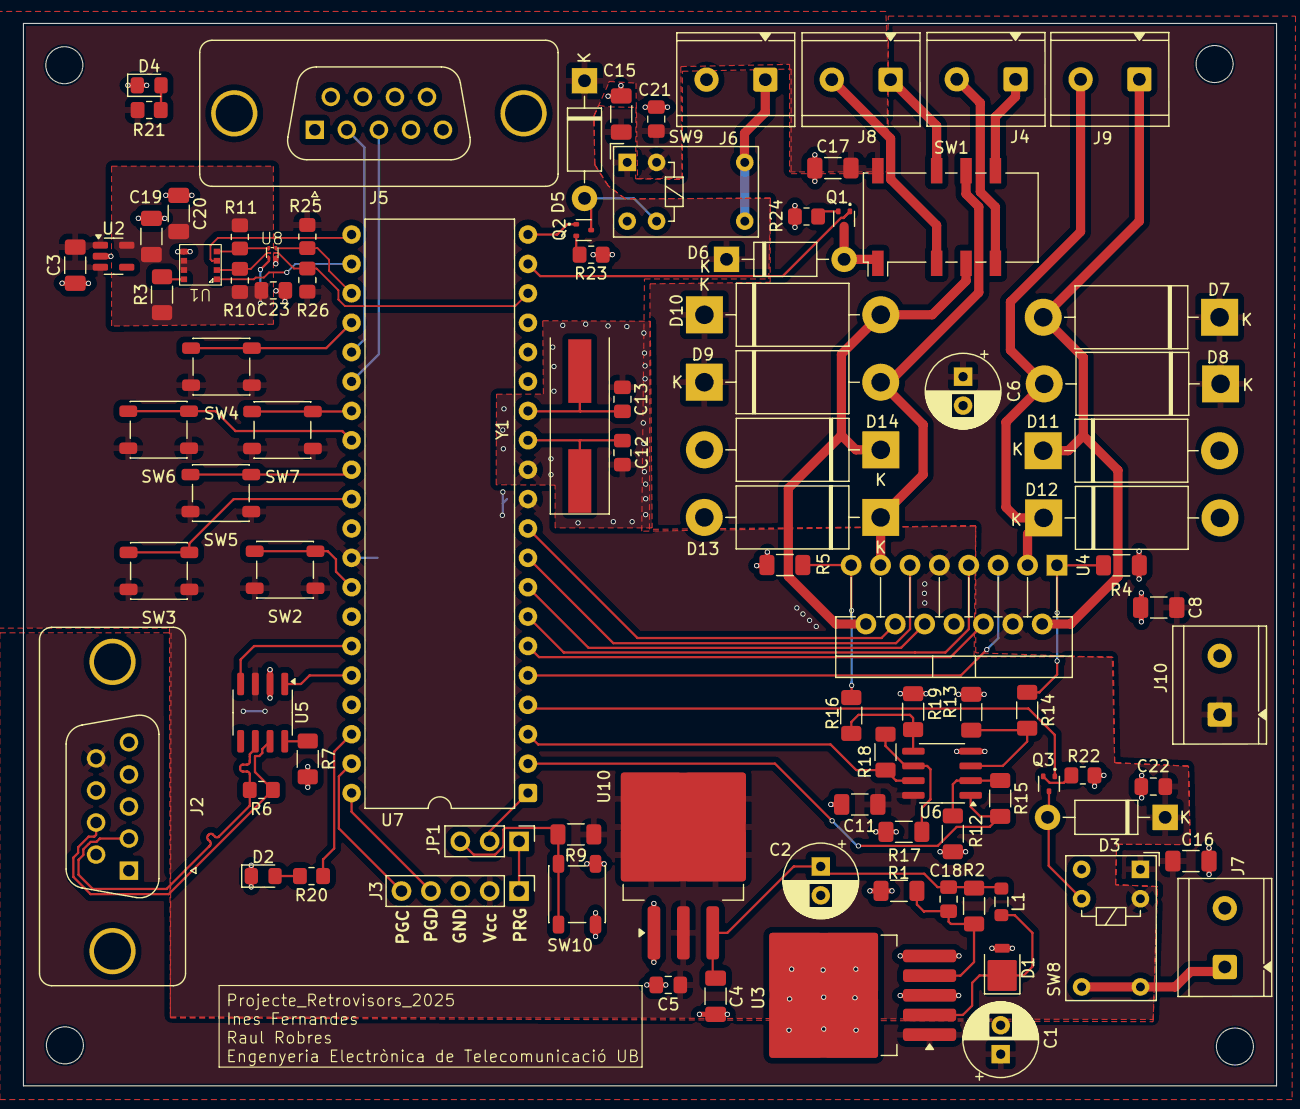
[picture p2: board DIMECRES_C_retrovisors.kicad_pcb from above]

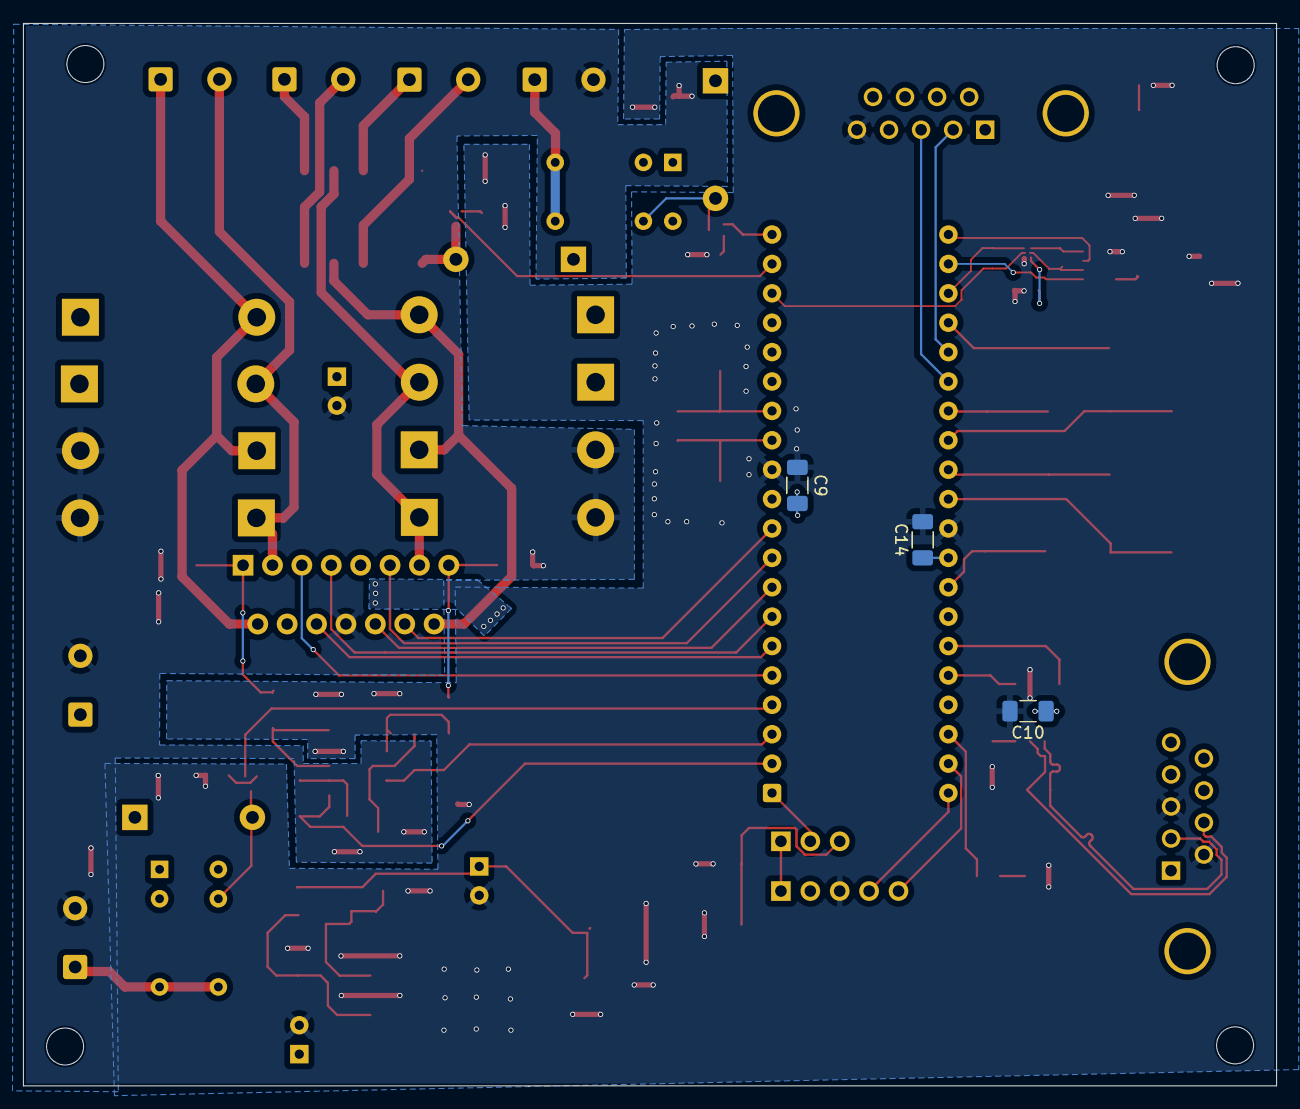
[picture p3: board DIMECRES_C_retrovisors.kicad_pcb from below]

Board: 2 copper layers, 108.3 x 91.8 mm, 95 parts (3 on the bottom side), 70 nets.

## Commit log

2025-03-19 Creacio projecte kicad
    [DIMECRES_C_retrovisors.kicad_pcb, DIMECRES_C_retrovisors.kicad_sch]
2025-03-20 Add schematic and pcb
    [DIMECRES_C_retrovisors.kicad_pcb, DIMECRES_C_retrovisors.kicad_sch]
2025-03-20 borrar todo
    [DIMECRES_C_retrovisors.kicad_pcb, DIMECRES_C_retrovisors.kicad_sch]
2025-03-20 Añadir sch+pcb
    [DIMECRES_C_retrovisors.kicad_pcb, DIMECRES_C_retrovisors.kicad_sch]
2025-03-20 prueba 2
    [DIMECRES_C_retrovisors.kicad_sch]
2025-03-22 Actualització llista material
2025-03-22 1/2Etapa reguladora
    [DIMECRES_C_retrovisors.kicad_sch]
2025-03-23 Regulador+1/3 Driver
    [DIMECRES_C_retrovisors.kicad_sch]
2025-03-23 Update README, change orientation of the BJT
    [DIMECRES_C_retrovisors.kicad_sch]
2025-03-24 Delete DIMECRES_C_retrovisors_24_03.kicad_sch
    nuevo modelo
    [DIMECRES_C_retrovisors_24_03.kicad_sch]
2025-03-24 Microcontrolador + edicion driver
    Esquematico Editado - driver + microcontrolador. Falta añadir sensores
    [DIMECRES_C_retrovisors.kicad_sch]
2025-03-24 Add diode + resistencia proteccio a MCLR
    Add diode + resistencia 10kOhms proteccio a MCLR. Resistencia Pull-up + diode de proteccio al pin MCLR
    [DIMECRES_C_retrovisors.kicad_sch]
2025-03-24 correccio errors
    [DIMECRES_C_retrovisors.kicad_sch]
2025-03-24 Upload sch
    [DIMECRES_C_retrovisors.kicad_sch]
2025-03-25 Update sch
    [DIMECRES_C_retrovisors.kicad_sch]
2025-03-25 Upd. sch. & Diag.
    [DIMECRES_C_retrovisors.kicad_sch]
2025-03-28 Up. sch.
    [DIMECRES_C_retrovisors.kicad_sch]
2025-03-29 Up de tot
    [DIMECRES_C_retrovisors.kicad_sch]
2025-03-29 UP SCH
    [DIMECRES_C_retrovisors.kicad_sch]
2025-03-30 Inicio Layout queda mucho aun...
    [DIMECRES_C_retrovisors.kicad_pcb, DIMECRES_C_retrovisors.kicad_sch]
2025-03-31 Todo el layout v1 ?
    [DIMECRES_C_retrovisors.kicad_pcb, DIMECRES_C_retrovisors.kicad_sch]
2025-04-01 Actu Layoutt
    [DIMECRES_C_retrovisors.kicad_pcb, DIMECRES_C_retrovisors.kicad_sch]
2025-04-02 Add files via upload
    Versió del diagrama de Blocs definitva. Incluint la distinció de les diferents Net Classes que tenim en el projecte. S'afegeixen colors per cadascuna i a mes a mes s'afegeix una llegenda que especifi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
2025-04-02 VERSIO DEL DIAGRAMA DE BLOCS SEPARAT PER CLASSES
    S'ha modificat el diagrama separant els tipus de classes que actualment tenim en el nostre projecte. Es diferencien les classes: power, analog i digital per colors i s'afegeix una llegenda que concre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
2025-04-03 Primeres MOdificacions Layout
    [DIMECRES_C_retrovisors.kicad_pcb]
2025-04-06 mod. lay.
    [DIMECRES_C_retrovisors.kicad_pcb]
2025-04-07 Modificacions Layout
    [DIMECRES_C_retrovisors.kicad_pcb]
2025-04-08 Proimeres correccions
    [DIMECRES_C_retrovisors.kicad_pcb, DIMECRES_C_retrovisors.kicad_sch]
2025-04-08 planos vcc
    [DIMECRES_C_retrovisors.kicad_pcb, DIMECRES_C_retrovisors.kicad_sch]
2025-04-08 Ns pero creo que asi se queda
    [DIMECRES_C_retrovisors.kicad_pcb]
2025-04-08 Asi se queda demomento
    [DIMECRES_C_retrovisors.kicad_pcb]
2025-04-09 Modificació de coses puntuals
    S'ha afegit el domini a la placa, s'han modificat algunes vies per tal de que sigui millor tan visualment com a nivell de funcionament dels components
2025-04-09 correccion errores
    [DIMECRES_C_retrovisors.kicad_pcb, DIMECRES_C_retrovisors.kicad_sch]
2025-04-14 De to
    [DIMECRES_C_retrovisors.kicad_pcb, DIMECRES_C_retrovisors.kicad_sch]
2025-04-20 ultims canvis
    [DIMECRES_C_retrovisors.csv]
2025-04-23 muchas cosas a ya...
    [DIMECRES_C_retrovisors-B_Cu.gbr, DIMECRES_C_retrovisors-B_Mask.gbr, DIMECRES_C_retrovisors-B_Paste.gbr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]
